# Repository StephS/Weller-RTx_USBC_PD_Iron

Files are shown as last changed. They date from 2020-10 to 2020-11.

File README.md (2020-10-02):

# Weller-RTx_USBC_PD_Iron
USB Type C Soldering Iron
Utilizes the ST Micro STM32G431 controller with USB Type C Power delivery support
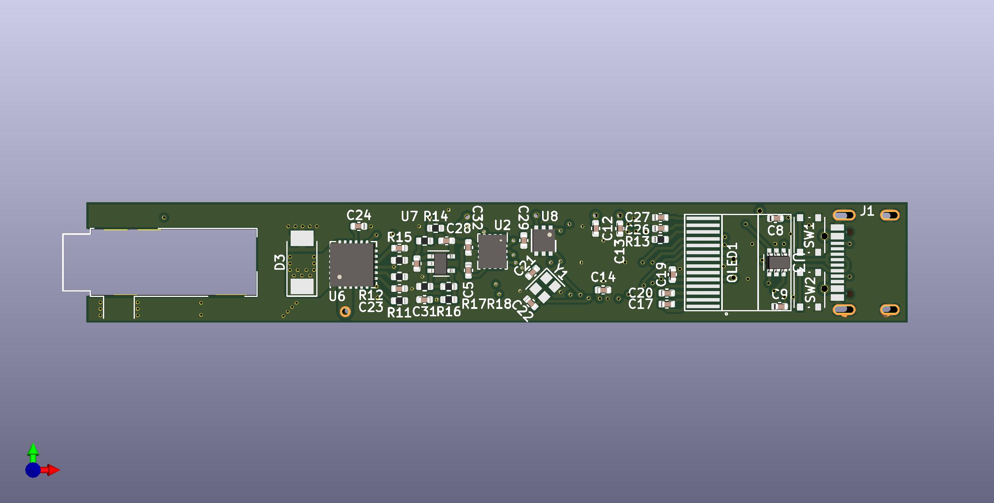
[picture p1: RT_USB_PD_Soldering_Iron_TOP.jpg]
Top

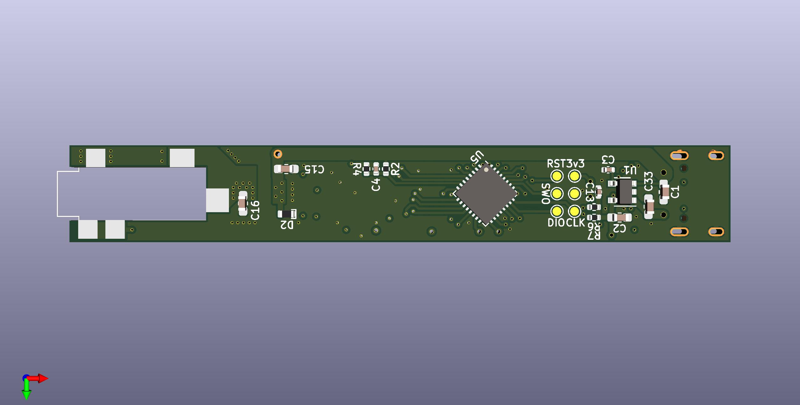
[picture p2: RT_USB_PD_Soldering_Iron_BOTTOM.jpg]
Bottom


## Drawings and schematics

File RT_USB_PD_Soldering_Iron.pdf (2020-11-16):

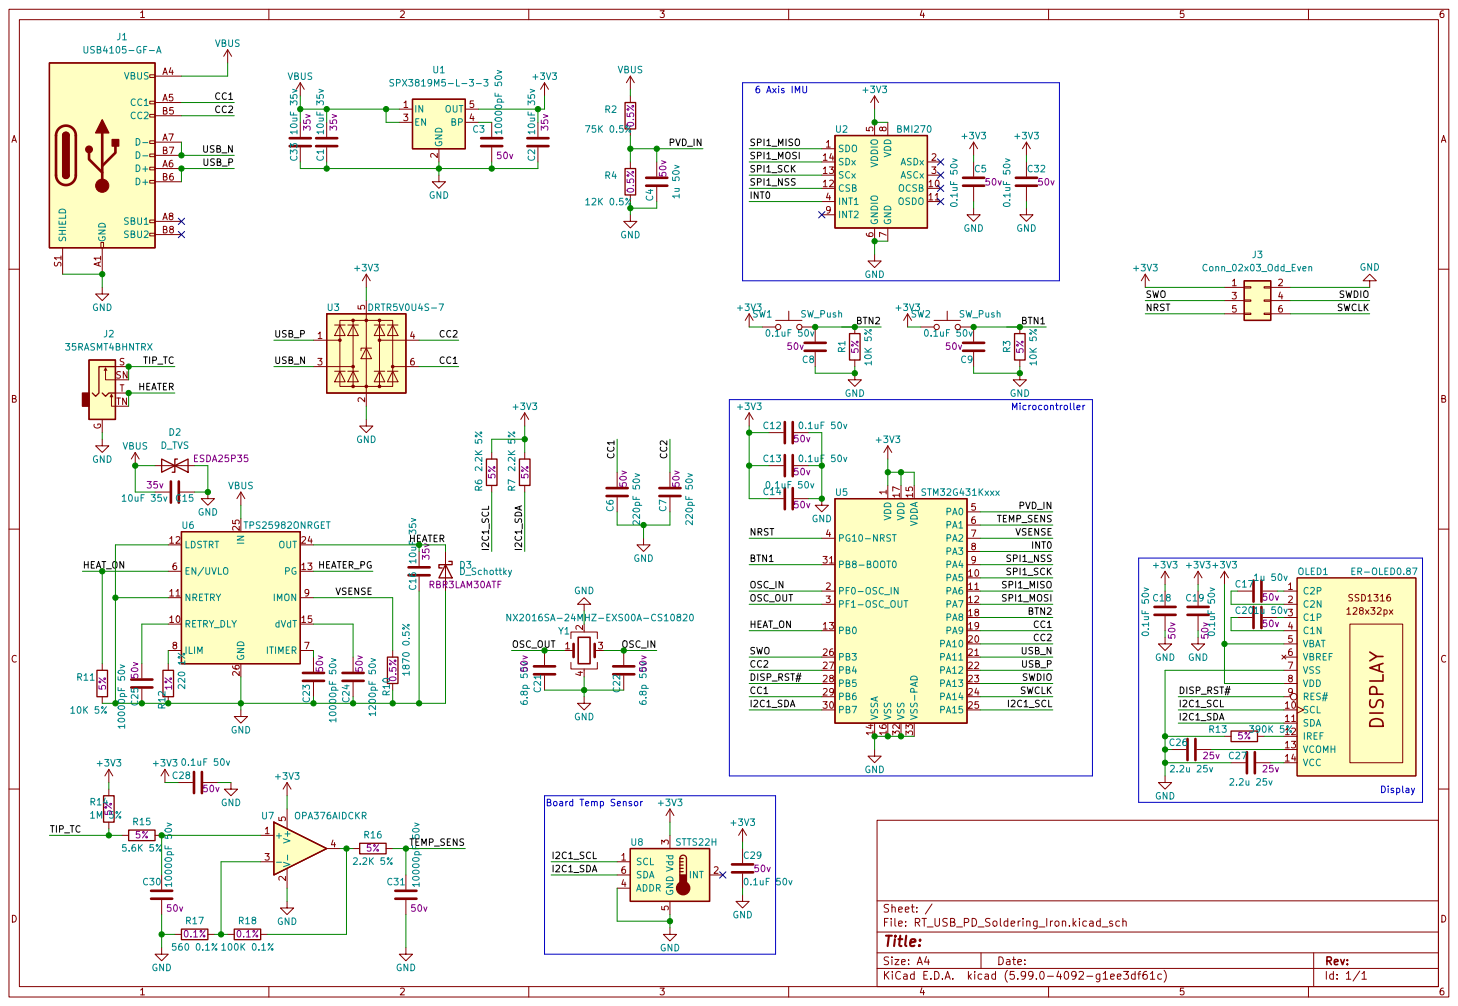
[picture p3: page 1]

2 EN 3 BP 4 OUT 5 U1 SPX3819M5-L-3-3 C41u 50v50v C3 10000pF 50v 50v R12 1%220 1% C24 1200pF 50v50v GND

1 VDD 17 VDDA 15 VSS 16 VSS 32 VSS-PAD 33 U5 STM32G431Kxxx C5 0.1uF 50v 50v SW2 SW_Push C32 0.1uF 50v 50v +3V3

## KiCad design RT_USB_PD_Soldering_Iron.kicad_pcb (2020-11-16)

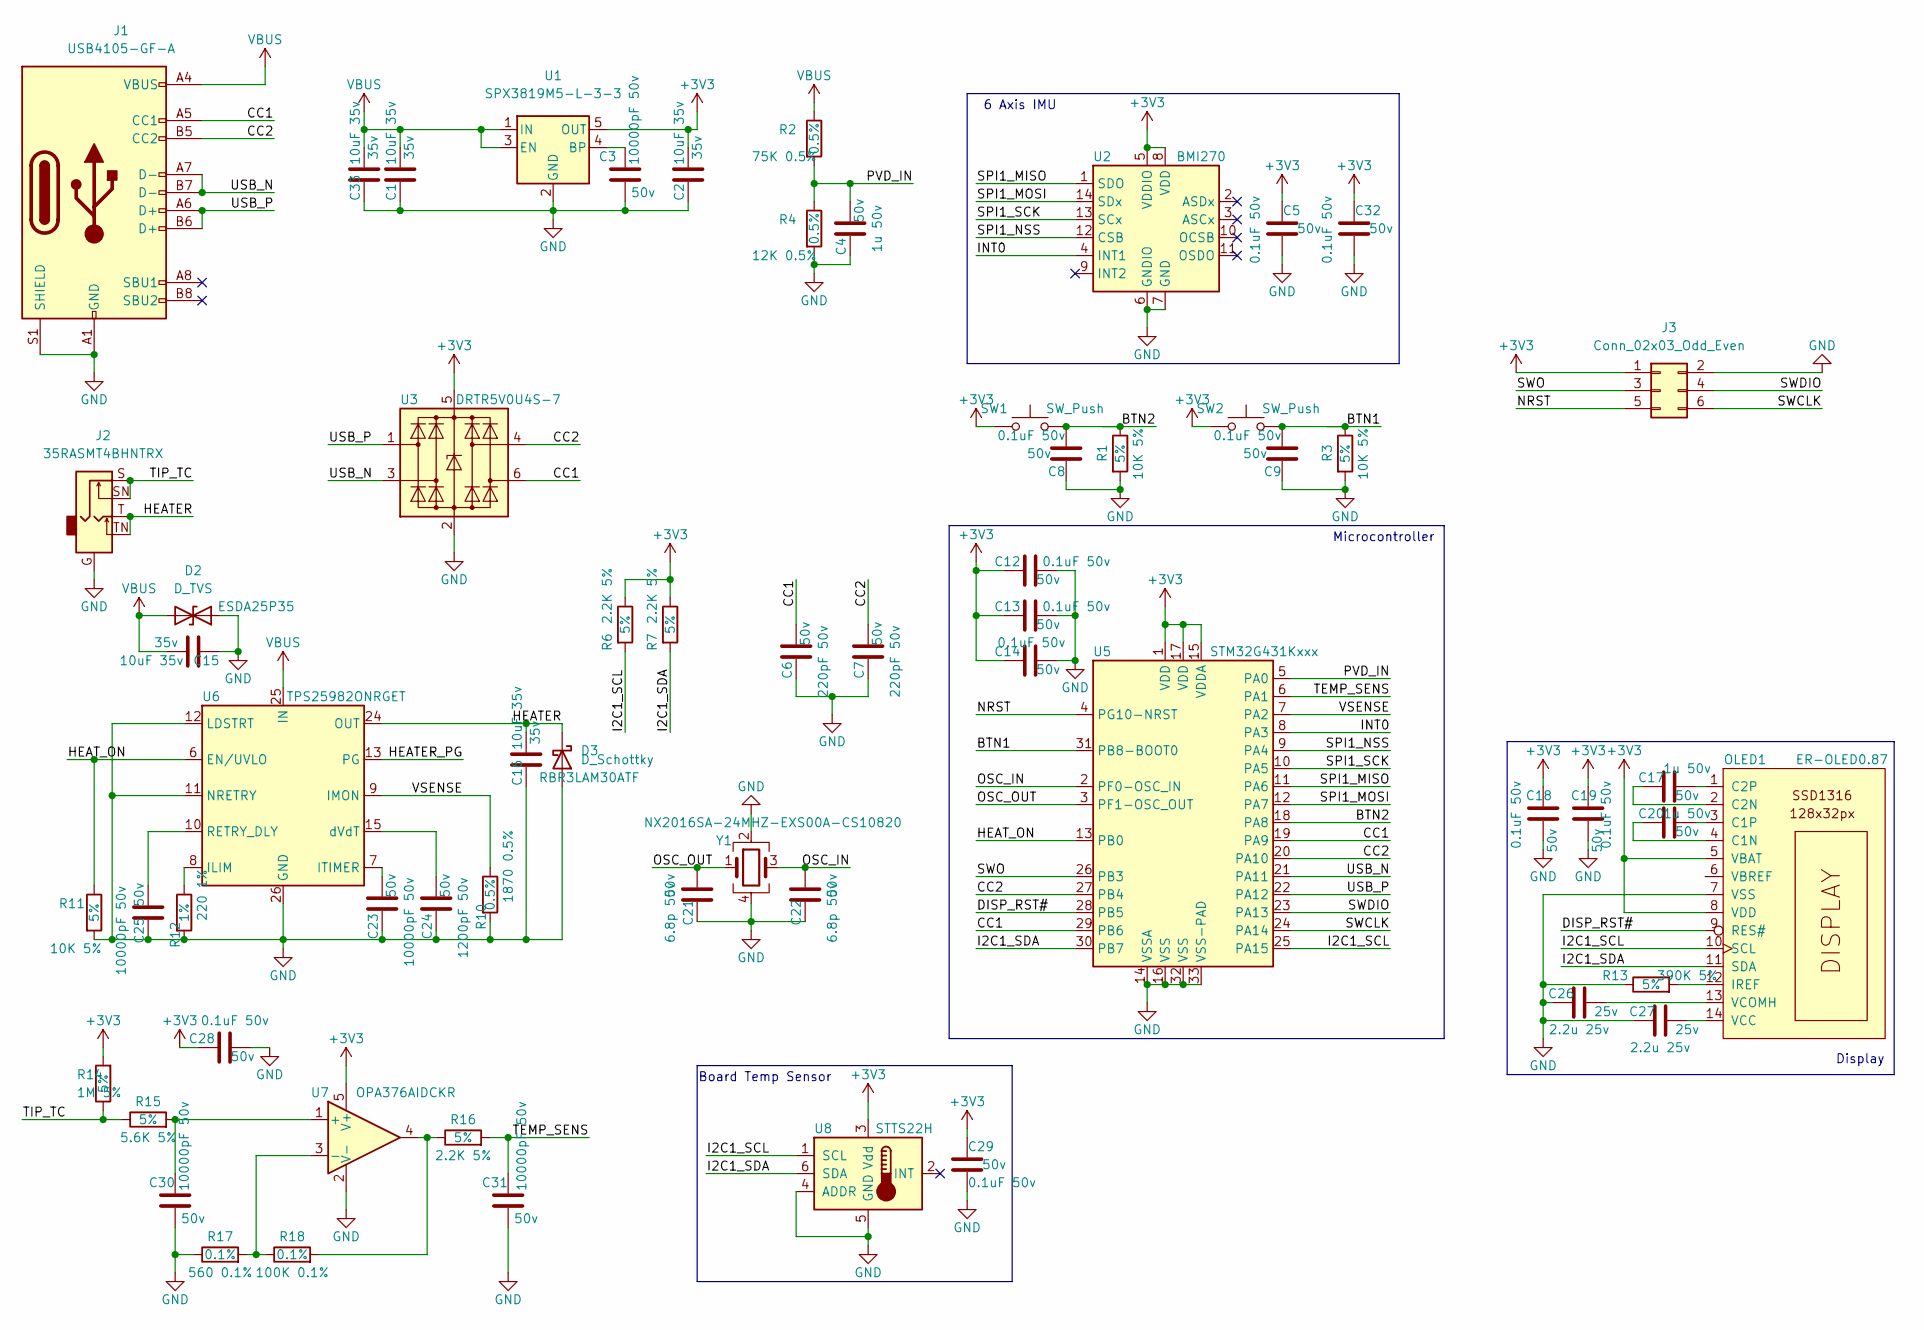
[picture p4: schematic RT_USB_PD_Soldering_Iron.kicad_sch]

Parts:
C1, C2, C15, C16, C33: 10uF 35v; C_0603_1608Metric_Pad1.05x0.95mm_HandSolder; Voltage 35v
C3, C23, C25, C30, C31: 10000pF 50v; C_0402_1005Metric; Voltage 50v
C4, C17, C20: 1u 50v; C_0402_1005Metric; Voltage 50v
C5, C8, C9, C12, C13, C14, C18, C19, C28, C29, C32: 0.1uF 50v; C_0402_1005Metric; Voltage 50v
C6, C7: 220pF 50v; C_0402_1005Metric; Voltage 50v
C21, C22: 6.8p 50v; C_0402_1005Metric; Voltage 50v
C24: 1200pF 50v; C_0402_1005Metric; Voltage 50v
C26, C27: 2.2u 25v; C_0402_1005Metric; Voltage 25v
D2: D_TVS; D_1610; Part ESDA25P35
D3: D_Schottky; D_SOD-128; Part RBR3LAM30ATF
J1: USB4105-GF-A; GCT_USB4105
J2: 35RASMT4BHNTRX; Jack_3.5mm_CUI_SJ-3524-SMT_Horizontal_cutout
J3: Conn_02x03_Odd_Even; PinHeader_2x03_P1.00mm_Vertical_SMD
OLED1: ER-OLED0.87
R1, R3, R11: 10K 5%; R_0402_1005Metric; Tolerance 5%
R2: 75K 0.5%; R_0402_1005Metric; Tolerance 0.5%
R4: 12K 0.5%; R_0402_1005Metric; Tolerance 0.5%
R6, R7, R16: 2.2K 5%; R_0402_1005Metric; Tolerance 5%
R10: 1870 0.5%; R_0402_1005Metric; Tolerance 0.5%
R12: 220 1%; R_0402_1005Metric; Tolerance 1%
R13: 390K 5%; R_0402_1005Metric; Tolerance 5%
R14: 1M 5%; R_0402_1005Metric; Tolerance 5%
R15: 5.6K 5%; R_0402_1005Metric; Tolerance 5%
R17: 560 0.1%; R_0402_1005Metric; Tolerance 0.1%
R18: 100K 0.1%; R_0402_1005Metric; Tolerance 0.1%
SW1, SW2: SW_Push; SW_Push_1P1T_NO_Vertical_Wuerth_434133025816
U1: SPX3819M5-L-3-3; SOT-23-5
U2: BMI270; Bosch_LGA-14_3x2.5mm_P0.5mm
U3: DRTR5V0U4S-7; SOT-363_SC-70-6
U5: STM32G431Kxxx; QFN-32-1EP_5x5mm_P0.5mm_EP3.45x3.45mm
U6: TPS25982ONRGET; VQFN-24-1EP_4x4mm_P0.5mm_EP2.45x2.45mm
U7: OPA376AIDCKR; SOT-353_SC-70-5
U8: STTS22H; DFN-6-1EP_2x2mm_P0.65mm_EP1x1.6mm
Y1: NX2016SA-24MHZ-EXS00A-CS10820; Crystal_SMD_2016-4Pin_2.0x1.6mm

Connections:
+3V3: C2.1, C5.1, C12.1, C13.1, C14.1, C18.1, C19.1, C28.1, C29.1, C32.1, J3.1, OLED1.5 (VBAT), OLED1.8 (VDD), R6.1, R7.1, R14.2, SW1.1, SW2.1, U1.5 (OUT), U2.5 (VDDIO), U2.8 (VDD), U3.5 (VBUS), U5.1 (VDD), U5.15 (VDDA), U5.17 (VDD), U7.5 (V+), U8.3 (Vdd)
/BTN1: C9.2, R3.1, SW2.2, U5.31 (PB8-BOOT0)
/BTN2: C8.2, R1.1, SW1.2, U5.18 (PA8)
/CC1: C6.2, J1.A5 (CC1), U3.6 (I/O4), U5.19 (PA9), U5.29 (PB6)
/CC2: C7.2, J1.B5 (CC2), U3.4 (I/O3), U5.20 (PA10), U5.27 (PB4)
/DISP_RST#: OLED1.9 (RES#), U5.28 (PB5)
/HEATER: C16.1, D3.1 (K), J2.T, J2.TN, U6.17 (OUT), U6.18 (OUT), U6.19 (OUT), U6.20 (OUT), U6.21 (OUT), U6.22 (OUT), U6.23 (OUT), U6.24 (OUT)
/HEATER_PG: U6.13 (PG)
/HEAT_ON: R11.1, U5.13 (PB0), U6.6 (EN/UVLO)
/I2C1_SCL: OLED1.10 (SCL), R6.2, U5.25 (PA15), U8.1 (SCL)
/I2C1_SDA: OLED1.11 (SDA), R7.2, U5.30 (PB7), U8.6 (SDA)
/INT0: U2.4 (INT1), U5.8 (PA3)
/NRST: J3.5, U5.4 (PG10-NRST)
/OSC_IN: C22.2, U5.2 (PF0-OSC_IN), Y1.3
/OSC_OUT: C21.2, U5.3 (PF1-OSC_OUT), Y1.1
/PVD_IN: C4.2, R2.2, R4.1, U5.5 (PA0)
/SPI1_MISO: U2.1 (SDO), U5.11 (PA6)
/SPI1_MOSI: U2.14 (SDx), U5.12 (PA7)
/SPI1_NSS: U2.12 (CSB), U5.9 (PA4)
/SPI1_SCK: U2.13 (SCx), U5.10 (PA5)
/SWCLK: J3.6, U5.24 (PA14)
/SWDIO: J3.4, U5.23 (PA13)
/SWO: J3.3, U5.26 (PB3)
/TEMP_SENS: C31.1, R16.2, U5.6 (PA1)
/TIP_TC: J2.S, J2.SN, R14.1, R15.1
/USB_N: J1.A7 (D-), J1.B7 (D-), U3.3 (I/O2), U5.21 (PA11)
/USB_P: J1.A6 (D+), J1.B6 (D+), U3.1 (I/O1), U5.22 (PA12)
/VSENSE: R10.1, U5.7 (PA2), U6.9 (IMON)
GND: C1.2, C2.2, C3.2, C4.1, C5.2, C6.1, C7.1, C8.1, C9.1, C12.2, C13.2, C14.2, C15.2, C16.2, C18.2, C19.2, C21.1, C22.1, C23.1, C24.1, C25.1, C26.1, C27.1, C28.2, C29.2, C30.2, C31.2, C32.2, C33.2, D2.1 (A1), D3.2 (A), J1.A1 (GND), J1.A12 (GND), J1.B1 (GND), J1.B12 (GND), J1.S1 (SHIELD), J2.G, J3.2, OLED1.7 (VSS), R1.2, R3.2, R4.2, R10.2, R11.2, R12.2, R13.1, R17.1, U1.2 (GND), U2.6 (GNDIO), U2.7 (GND), U3.2 (GND), U5.14 (VSSA), U5.16 (VSS), U5.32 (VSS), U5.33 (VSS-PAD), U6.4 (GND), U6.5 (GND), U6.11 (NRETRY), U6.12 (LDSTRT), U6.14 (GND), U6.26 (GND), U7.2 (V-), U8.4 (ADDR), U8.5 (GND), U8.7 (GND), Y1.2, Y1.4
IN: C1.1, C15.1, C33.1, D2.2 (A2), J1.A4 (VBUS), J1.A9 (VBUS), J1.B4 (VBUS), J1.B9 (VBUS), R2.1, U1.1 (IN), U1.3 (EN), U6.1 (IN), U6.2 (IN), U6.3 (IN), U6.16 (IN), U6.25 (IN)
unnamed: C3.1, U1.4 (BP)
unnamed: C17.1, OLED1.2 (C2N)
unnamed: C17.2, OLED1.1 (C2P)
unnamed: C20.1, OLED1.4 (C1N)
unnamed: C20.2, OLED1.3 (C1P)
unnamed: C23.2, U6.7 (ITIMER)
unnamed: C24.2, U6.15 (dVdT)
unnamed: C25.2, U6.10 (RETRY_DLY)
unnamed: C26.2, OLED1.13 (VCOMH)
unnamed: C27.2, OLED1.14 (VCC)
unnamed: C30.1, R15.2, U7.1 (+)
unnamed: OLED1.12 (IREF), R13.2
unnamed: R12.1, U6.8 (ILIM)
unnamed: R16.1, R18.2, U7.4
unnamed: R17.2, R18.1, U7.3 (-)

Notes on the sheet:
Board Temp Sensor
6 Axis IMU
Microcontroller
Display

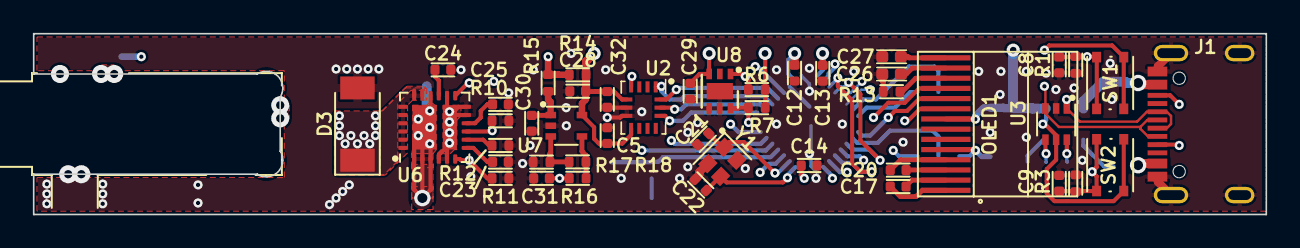
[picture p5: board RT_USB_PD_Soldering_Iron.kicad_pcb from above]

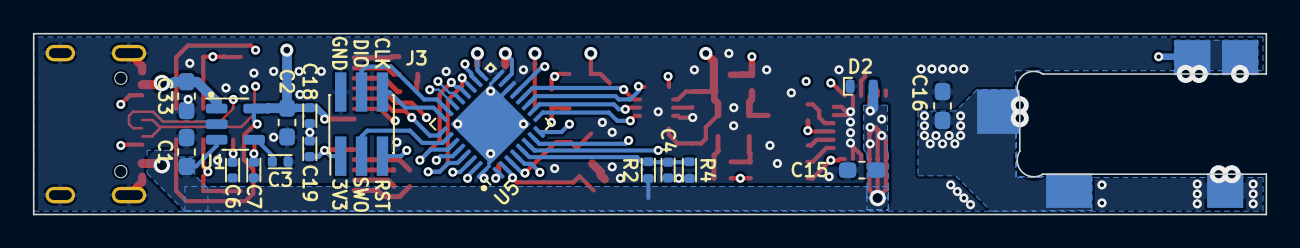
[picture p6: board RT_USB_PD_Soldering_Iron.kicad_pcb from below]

Board: 4 copper layers, 75.0 x 11.0 mm, 62 parts (17 on the bottom side), 44 nets.

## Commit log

2020-09-21 First revision
    First revision, to be reviewed
    [RT_USB_PD_Soldering_Iron.kicad_pcb, RT_USB_PD_Soldering_Iron.kicad_sch]
2020-09-21 Add Schematic
    Add Schematic and minor layout changes
    [RT_USB_PD_Soldering_Iron.kicad_pcb]
2020-09-21 Adjust for oled cable
    added some room for the oled bend radius.
    [RT_USB_PD_Soldering_Iron.kicad_pcb]
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2020-09-24 New board layout
    New layout. Nothing is around the USB connector now. 1mm keepout around the entire board edge. I actually like this layout!
    [RT_USB_PD_Soldering_Iron.kicad_pcb, RT_USB_PD_Soldering_Iron.kicad_sch]
2020-09-24 Fix button position
    one button was off by 0.5mm LED position was off too...
    [RT_USB_PD_Soldering_Iron.kicad_pcb]
2020-09-24 Update silkscreen
    Update silkscreen, minor layour changes
    [RT_USB_PD_Soldering_Iron-B_Cu.gbl, RT_USB_PD_Soldering_Iron-B_Mask.gbs, RT_USB_PD_Soldering_Iron-B_SilkS.gbo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]
2020-09-30 Update Headphone connector footprint
    updating the footprint based on actual measurements.
    [RT_USB_PD_Soldering_Iron-B_Cu.gbl, RT_USB_PD_Soldering_Iron-B_Mask.gbs, RT_USB_PD_Soldering_Iron-B_SilkS.gbo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]
2020-09-30 widen cut for microphone jack
    widen the cut by 0.1mm
    [RT_USB_PD_Soldering_Iron-B_Cu.gbl, RT_USB_PD_Soldering_Iron-B_Mask.gbs, RT_USB_PD_Soldering_Iron-B_SilkS.gbo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]
2020-09-30 Improve XTAL circuit
    reduce the length of the xtal traces, move capacitors, and ensure GND encapsulation.
    Via diameter has been reduced to .605 from .7
    [RT_USB_PD_Soldering_Iron-B_Cu.gbl, RT_USB_PD_Soldering_Iron-B_Mask.gbs, RT_USB_PD_Soldering_Iron-B_SilkS.gbo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]
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2020-10-01 Add updated board
    Length set to 90mm!
    [RT_USB_PD_Soldering_Iron.kicad_pcb]
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2020-10-03 Removed LED and reduced size to 80mm
    Shortest!
    [RT_USB_PD_Soldering_Iron.kicad_sch]
2020-10-03 add fpc connector
    it's slightly smaller, so maybe good?
    [RT_USB_PD_Soldering_Iron.kicad_pcb]
2020-10-04 Reduce board to 75mm length
    Knocked off another 5mm
    modified USB connector pads. Increased connector board edge to meet 1mm overhang.
    Replaced a few components with new ones (smaller, lower cost).
    VReg, Usb ESD protection, and Op-AMP.
    [RT_USB_PD_Soldering_Iron.kicad_pcb, RT_USB_PD_Soldering_Iron.kicad_sch]
2020-10-04 change analog pins for improved routing
    [RT_USB_PD_Soldering_Iron.kicad_pcb, RT_USB_PD_Soldering_Iron.kicad_sch]
2020-10-05 Update silkscreen and gerbers
    moved parts a tiny bit for easier hand soldering.
    [RT_USB_PD_Soldering_Iron-B_Cu.gbl, RT_USB_PD_Soldering_Iron-B_Mask.gbs, RT_USB_PD_Soldering_Iron-B_Paste.gbp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]
2020-10-06 Move buttons away from USB connector
    Was able to move the OLED display by 0.5mm and moved the buttons 0.5mm further from the connector.
    [RT_USB_PD_Soldering_Iron-B_Cu.gbl, RT_USB_PD_Soldering_Iron-B_Mask.gbs, RT_USB_PD_Soldering_Iron-B_Paste.gbp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]
2020-10-06 Adjust Silk and run DRC
    [RT_USB_PD_Soldering_Iron-B_Cu.gbl, RT_USB_PD_Soldering_Iron-B_Mask.gbs, RT_USB_PD_Soldering_Iron-B_Paste.gbp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]
2020-10-10 Update to latest nightly
    Application: KiCad
    Version: (5.99.0-3809-g61f1f7d948), release build
    Libraries:
    wxWidgets 3.0.5
    libcurl/7.71.0 OpenSSL/1.1.1g (Schannel) zlib/1.2.11 brotli/1.0.7 libidn2/2.3.0 libpsl/0.21.0 (+libidn2/2.3.0) libssh2/1.9.0 nghttp2/1.41.0
    Platform: Windows 8 (build 9200), 64-bit edition, 64 bit, Little endian, wxMSW
    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
    [RT_USB_PD_Soldering_Iron.kicad_pcb]
2020-10-18 update libs/parts
    update 0402 footprints for silkscreen
    move volate/tolerance to value
    [RT_USB_PD_Soldering_Iron.kicad_pcb, RT_USB_PD_Soldering_Iron.kicad_sch]
2020-10-19 Minor changes
    moved oled connector slightly. Moved I2C pullup resistors
    [RT_USB_PD_Soldering_Iron.kicad_pcb]
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2020-10-20 redo USB traces with impedence calculations
    rename usb traces and do calculations for 90 ohm impedence
    also change voltage sense resistors to higher values
    [RT_USB_PD_Soldering_Iron.kicad_pcb, RT_USB_PD_Soldering_Iron.kicad_sch]
2020-10-20 complete ground path for usb
    [RT_USB_PD_Soldering_Iron.kicad_pcb]
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2020-10-21 Add castellated holes, improve connector cutout and pad placement
    castellated holes to hopefully increase mechanical stability.
    cut into corners
    update schematic PDF.
    [RT_USB_PD_Soldering_Iron.kicad_pcb]
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2020-10-22 remove test points and replace with connector. fix USB nets
    also adjust default thermals for zone, sync pcb with schematic
    [RT_USB_PD_Soldering_Iron.kicad_pcb, RT_USB_PD_Soldering_Iron.kicad_sch]
2020-10-22 Update gerbers for release. 75mm_V2 sent to OshPark
    [RT_USB_PD_Soldering_Iron-B_Cu.gbl, RT_USB_PD_Soldering_Iron-B_Mask.gbs, RT_USB_PD_Soldering_Iron-B_Paste.gbp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]
2020-10-22 Update buttons to use active-high
    by using active high, button1 allows boot mode selection when pressed.
    [RT_USB_PD_Soldering_Iron.kicad_pcb, RT_USB_PD_Soldering_Iron.kicad_sch]
2020-10-22 update gerbers to v3
    [RT_USB_PD_Soldering_Iron-B_Cu.gbl, RT_USB_PD_Soldering_Iron-B_Mask.gbs, RT_USB_PD_Soldering_Iron-B_Paste.gbp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]
2020-10-23 Group all used footprints in a local library
    [RT_USB_PD_Soldering_Iron.kicad_pcb]
2020-10-24 Update Power voltage circuit to higher precision and lower cost components
    change to 12K + 75K 0.5%
    [RT_USB_PD_Soldering_Iron.kicad_pcb, RT_USB_PD_Soldering_Iron.kicad_sch]
2020-10-29 update thermals for high side switch
    or more accurately, add thermals. Previously difficult to hand solder. Hopefully this helps.
    [RT_USB_PD_Soldering_Iron.kicad_pcb]
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2020-10-29 Update footprints for R26, R27
    These 2.2uF capacitors are slightly larger than normal. Requires bigger pads.
    [RT_USB_PD_Soldering_Iron.kicad_pcb]
2020-10-30 Modify CC lines
    Add capacitors to CC lines. Tie in DBCC to the CC lines.
    [RT_USB_PD_Soldering_Iron.kicad_pcb, RT_USB_PD_Soldering_Iron.kicad_sch]
2020-10-30 New gerbers and schematics
    To be built
    [RT_USB_PD_Soldering_Iron-B_Cu.gbl, RT_USB_PD_Soldering_Iron-B_Mask.gbs, RT_USB_PD_Soldering_Iron-B_Paste.gbp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]
2020-10-30 slight change in capacitor layout
    [RT_USB_PD_Soldering_Iron-B_Cu.gbl, RT_USB_PD_Soldering_Iron-B_Mask.gbs, RT_USB_PD_Soldering_Iron-B_Paste.gbp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]
